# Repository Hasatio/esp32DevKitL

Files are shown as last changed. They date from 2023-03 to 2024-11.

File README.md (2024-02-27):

# ESP32-DEVKIT-L

The circuit taken as an example while designing the board [Olimex ESP32-Gateway](https://www.olimex.com/Products/IoT/ESP32/ESP32-GATEWAY)

## Revision 0

### Added:
- 1x TCA9548 mux IC
- 8x QWIIC connector
- 2x2 Molex connector for for external power supply
- 1x K7805-2000R3L or K7805-2000R3 for 5v convert
- Logo

### Changed:
- Type C
- ESP32-WROOM-32D model
- K7803-2000R3L or K7803-2000R3 for 5V to 3.3V convert
- Texts in pinout

## Revision 1

### Added:
- QWIIC connector pinout

## Revision 2

### Changed:
- Led GPIO33 to GPIO35
- PCA9548's SDA pin GPIO16 to GPIO33

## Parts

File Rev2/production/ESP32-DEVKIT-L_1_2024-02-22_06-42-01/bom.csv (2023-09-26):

Designator | Footprint | Quantity | Value | LCSC Part #
_2, |  | 2
BUT1, RST1 | T1107A(6x3,8x2,5MM) | 2 | T1107A(6x3,8x2,5MM)
C1 | CP_Elec_10x10.5 | 1 | 220uF/50V/10*10mm
C10, C13, C2, C5, C6 | 0603 | 5 | 22uF/6.3V/20%/X5R/C0603
C11, C19, C21 | 1210 | 3 | 330uF/6.3V/20%/X5R/C1210
C12, C14, C15, C16, C18, C23, C7 | 0603 | 7 | 100nF/50V/20%/Y5V/C0603
C17 | 0603 | 1 | 2.2uF/6.3V/10%/X5R/C0603
C20 | 0603 | 1 | NA(10uF/6.3V/20%/X5R/C0603)
C22 | 0603 | 1 | 1uF/C0603
C24 | 0805 | 1 | 47uF/6.3V/20%/X5R/C0805
C25, C26, C27, C28, C29, C30, C31, C32 | 0603 | 8 | 1uF/6.3V/20%/X5R/C0603
C3 | 1206 | 1 | 1nF/2000V/10%/X7R/C1206
C4 | 1206 | 1 | NA(1nF/2000V/10%/X7R/C1206)
C8, C9 | 0603 | 2 | 27pF/50V/5%/C0G/C0603
CON1 | HN1x20 | 1 | NA(NH1x20)
D1 | SMA-KA | 1 | 1N5822/SS34/SMA
D2 | DO214AA_1(K)-2(A) | 1 | SMBJ6.0A(DO-214AA)
D3, D4 | SOD-123_1C-2A_KA | 2 | 1N5819S4/SOD123
D5 | SOT23-3 | 1 | BAT54C(SOT23-3)
FET1, FET2 | SOT23 | 2 | WPM2015-3/TR
GND1 | TESTPAD_40-ROUND | 1 | TESTPAD
I²C0, I²C1, I²C2, I²C3, I²C4, I²C5, I²C6, I²C7 | JST_SH_SM04B-SRSS-TB_1x04-1MP_P1.00mm_Horizontal | 8 | Conn_01x04_P1.00mm_Stemma qt/Qwiic
J1 | Molex_Mini-Fit_Jr_5569-04A1_2x02_P4.20mm_Horizontal | 1 | Conn_02x02_P4.20mm_Molex_Horizontal
L1, L2, L3 | L_0805_5MIL_DWS | 3 | FB0805/600R/2A
LAN1 | RJLBC-060TC1 | 1 | RJLD-060TC1(LPJ4013EDNL)
LED | SJ | 1 | Closed
LED1 | LED_0603_KA | 1 | LED/GREEN/0603
MH1, MH2 | Mounting_hole_Shield_3.3mm | 2 | Mounting_hole_Shield_3.3mm
MICRO_SD1 | TFC-WXCP11-08-LF | 1 | TFC-WXCP11-08-LF
PWRLED1 | LED_0603_KA | 1 | LED/RED/0603
Q1 | Q_49U3HMS | 1 | Q12MHz/20pF/30ppm/2P/HC-49SM(SMD)
Q2, Q3 | SOT23 | 2 | BC817-40(SOT23)
R1, R15, R16 | 0603 | 3 | 1k/R0603
R10, R7, R8, R9 | 0603 | 4 | 49.9R/1%/R0603
R11, R12, R18, R2, R20, R22, R27, R52 | 0603 | 8 | 10k/R0603
R13 | 0603 | 1 | 1M/R0603
R14, R21, R23, R24, R25, R37 | 0603 | 6 | 2.2k/R0603
R17, R40, R51 | 0603 | 3 | 220R/R0603
R19 | 0603 | 1 | 12.1k/1%/R0603
R26, R28, R29, R30, R31, R32, R33, R34, R35, R36, R43, R44, R45, R46, R47, R48, R49, R50 | 0603 | 18 | 4.7k/R0603
R3, R4 | 0603 | 2 | 5.1k/R0603
R38, R41, R42, R53 | 0603 | 4 | NA/R0603
R39 | 0603 | 1 | 10R/R0603
R5, R6 | 0603 | 2 | 330R/R0603
RESET | SJ | 1 | Opened
RM1, RM2 | R_MATRIX_4 | 2 | RA1206_(4X0603)_4B8_2.2k
Sign-Antistatic | LOGO_ANTISTATIC_1 | 1 | Val**
Sign-RecyclBin | LOGO_RECYCLEBIN_1 | 1
Sign_Pb-Free | LOGO_PBFREE | 1
Sign_RoHS | LOGO_ROHS_1 | 1 | Val**
T1 | SOT23 | 1 | DTC114YKA
U1 | USB2.0_TYPE-C(A40-00119-A52-12) | 1 | USB-C-16P-F(A40-00119-A52-12)
U2 | Converter_DCDC_RECOM_R-78HB-0.5L_THT | 1 | K7805-2000R3L
U3 | SSOP-20W | 1 | CH340T(SSOP20W)
U4 | QFN32_EP(33)_5.00x5.00x0.90mm_Pitch_0.50mm | 1 | LAN8710A-EZC(QFN32)
U5 | Converter_DCDC_RECOM_R-78HB-0.5L_THT | 1 | K7803-2000R3L
U6 | TSSOP-24_4.4x7.8mm_P0.65mm | 1 | TCA9548APWR
U7 | ESP-WROOM-32_MODULE | 1 | ESP32-WROOM-32D-4MB

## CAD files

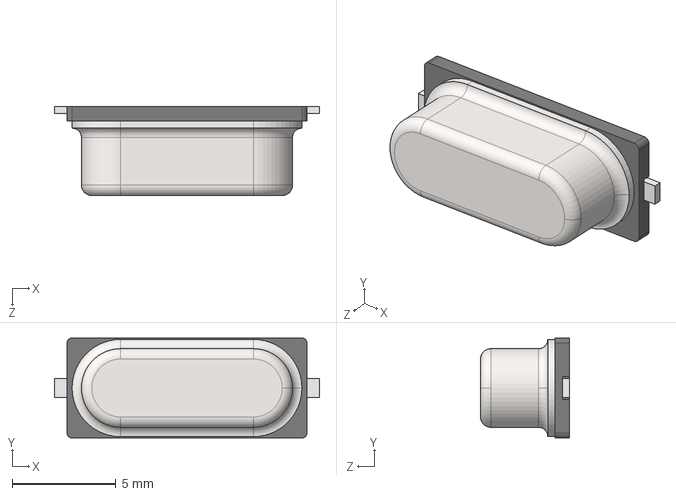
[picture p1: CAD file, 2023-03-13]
Rev2/3d/User_Library-Crystal_HC49_US-SM.step
12.8 x 4.83 x 4.30 mm

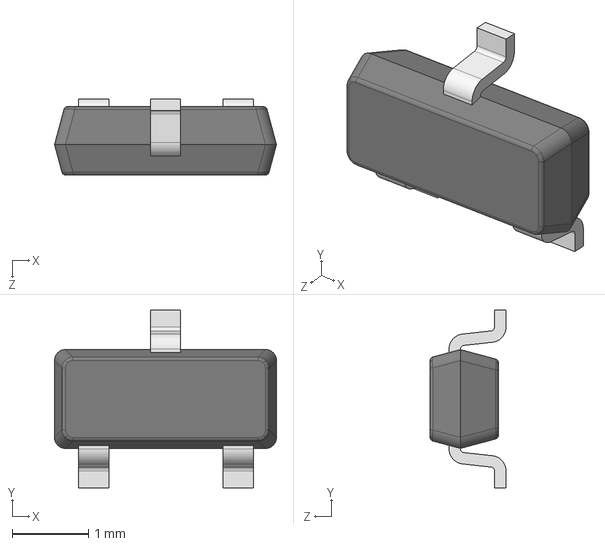
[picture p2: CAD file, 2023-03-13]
Rev2/3d/BAT54.step
2.92 x 2.34 x 1.00 mm

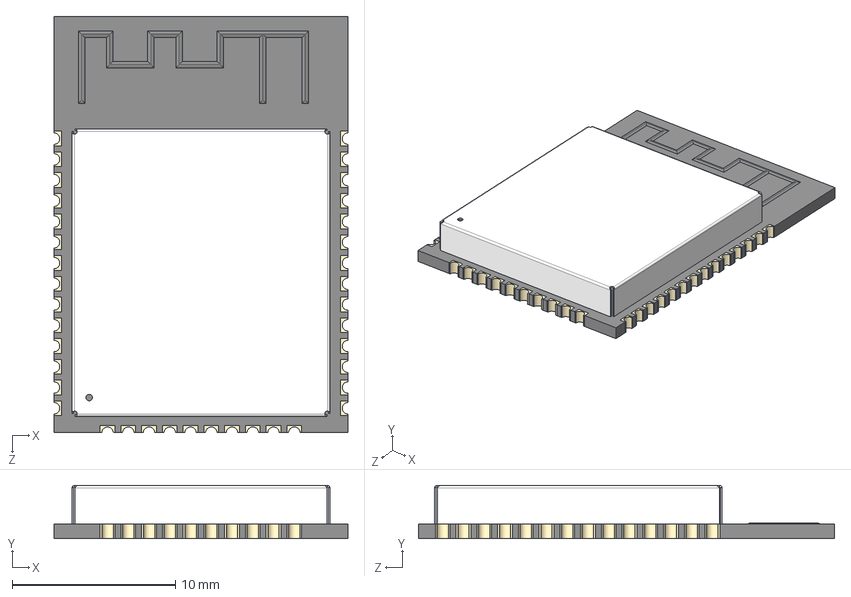
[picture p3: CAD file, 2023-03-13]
Rev2/3d/ESP32-WROOM-32D-56544.STEP
18.0 x 3.25 x 25.5 mm

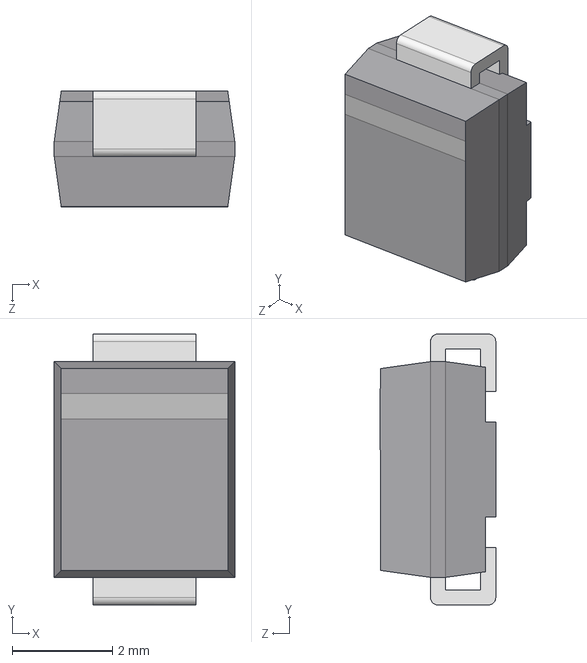
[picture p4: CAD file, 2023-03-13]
Rev2/3d/DO-214AA_SMB.step
3.60 x 5.40 x 2.30 mm

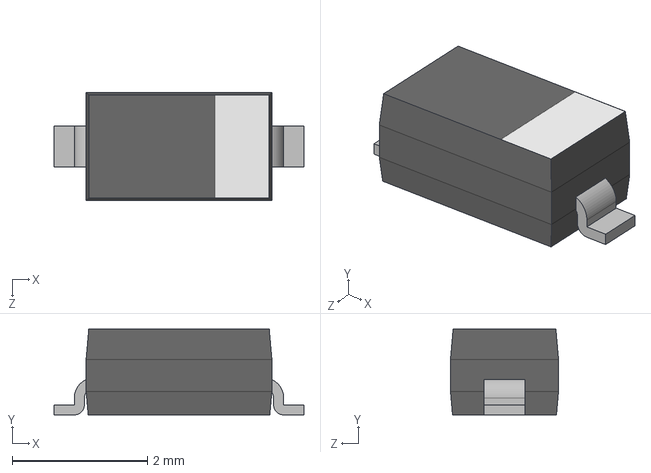
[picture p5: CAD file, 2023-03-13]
Rev2/3d/SOD123.step
3.70 x 1.27 x 1.60 mm

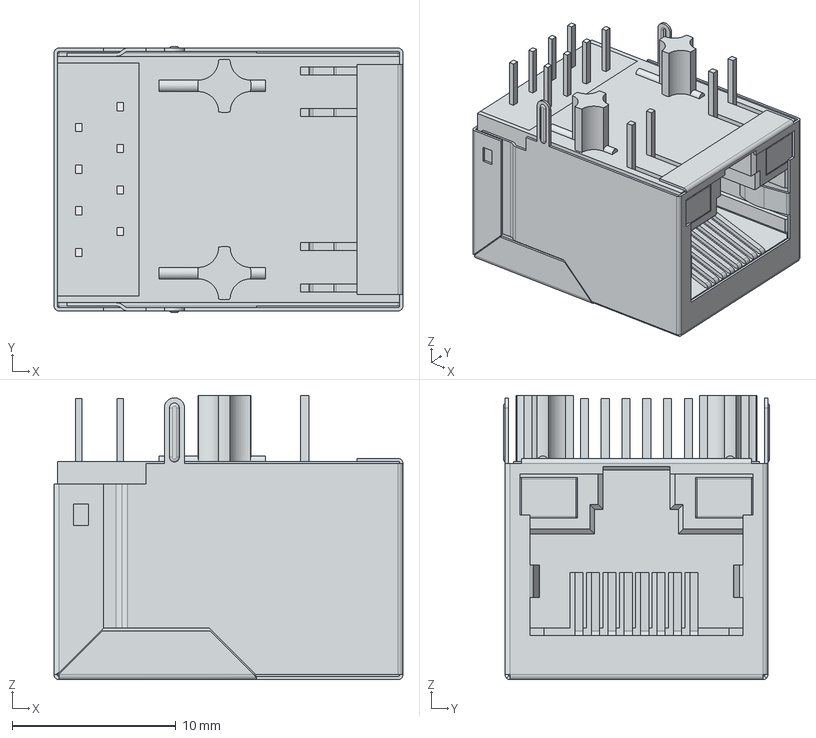
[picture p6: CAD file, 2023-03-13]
Rev2/3d/Connector_1Port_RJ45_Magjack_10-100Base-T_AutoMDIX_Wurth_Electronics-7499010441.stp
21.3 x 16.2 x 17.4 mm
Shielding
Insulator 3
Insulator 1
Insulator 2
Green_Yellow_LED x 2

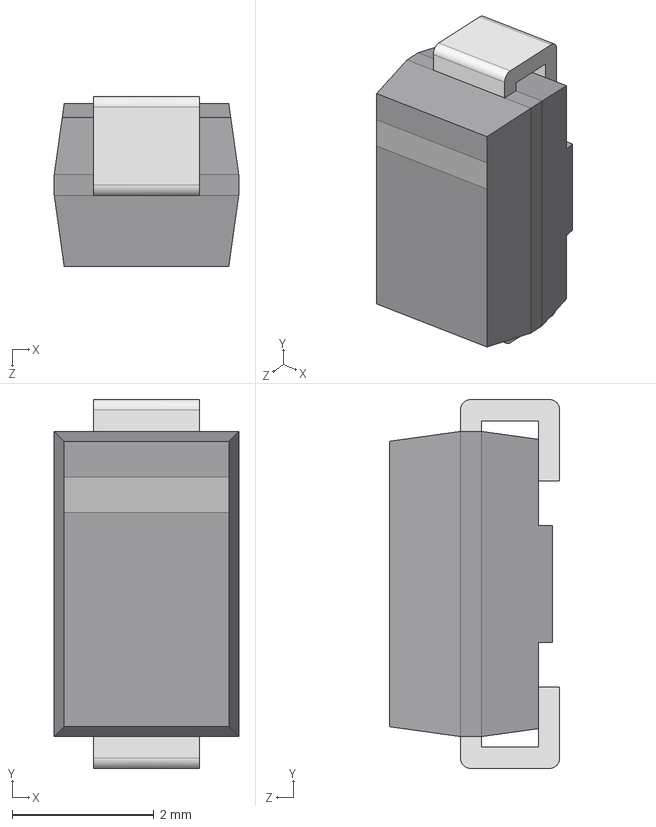
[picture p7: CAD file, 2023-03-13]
Rev2/3d/DO-214AC_SMA.step
2.60 x 5.20 x 2.40 mm

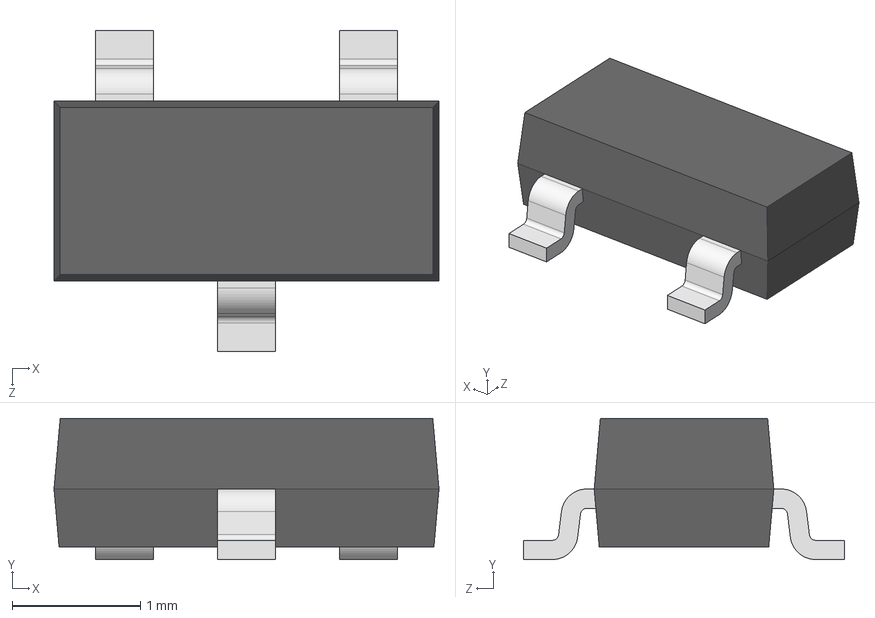
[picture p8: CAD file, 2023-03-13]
Rev2/3d/SOT-23.step
3.00 x 1.10 x 2.50 mm

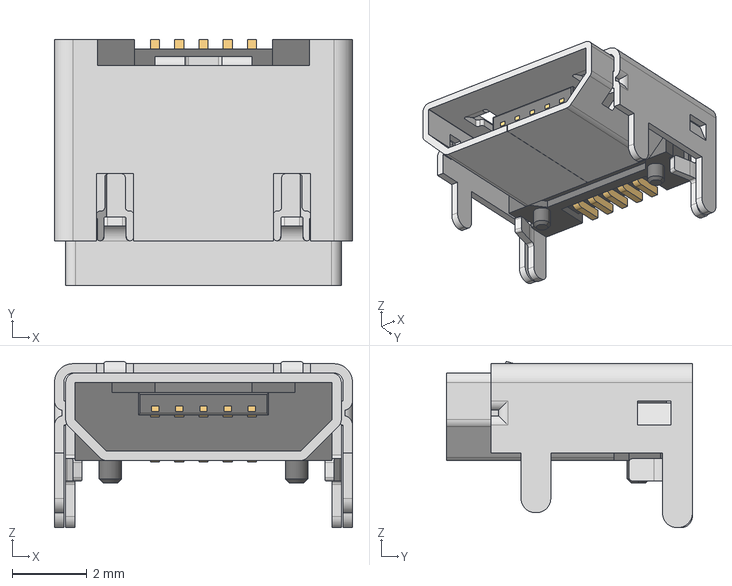
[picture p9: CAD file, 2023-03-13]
Rev2/3d/usb_micro_4p.stp
8.00 x 6.60 x 4.46 mm

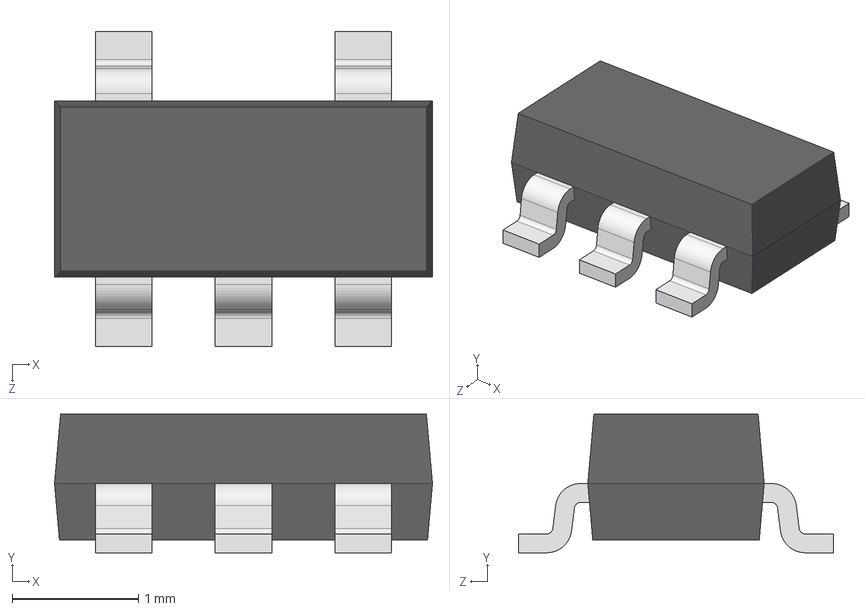
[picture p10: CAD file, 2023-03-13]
Rev2/3d/SOT-23-5.step
3.00 x 1.10 x 2.50 mm

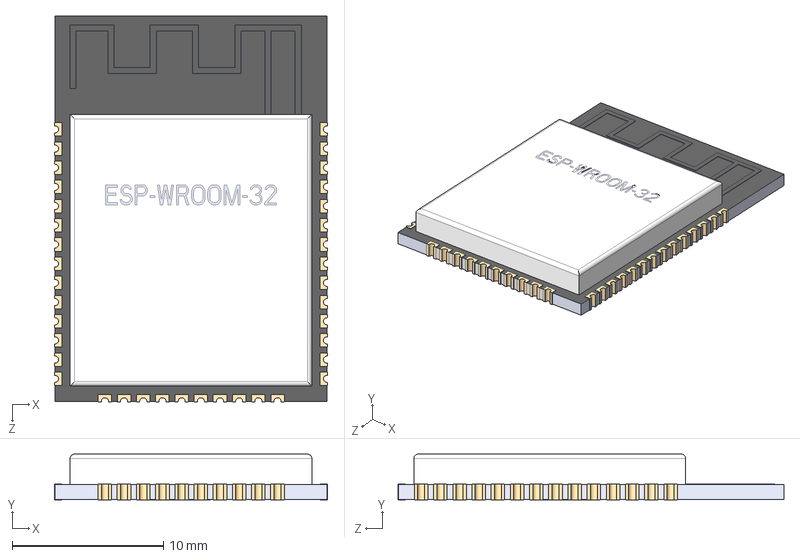
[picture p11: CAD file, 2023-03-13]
Rev2/3d/esp-wroom-32.step
18.1 x 3.04 x 25.5 mm

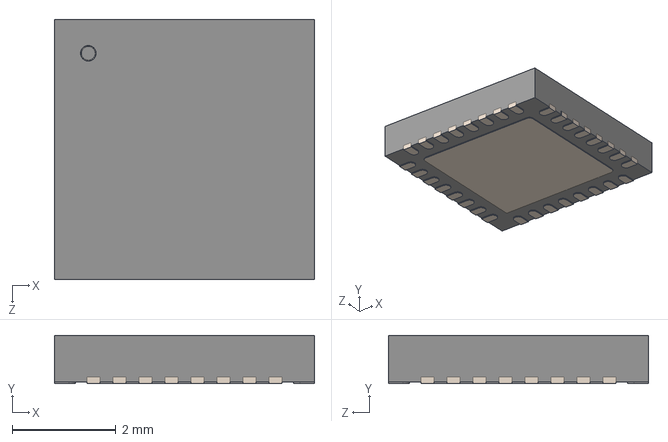
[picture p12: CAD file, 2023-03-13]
Rev2/3d/QFN32_5x5.step
5.00 x 0.93 x 5.00 mm

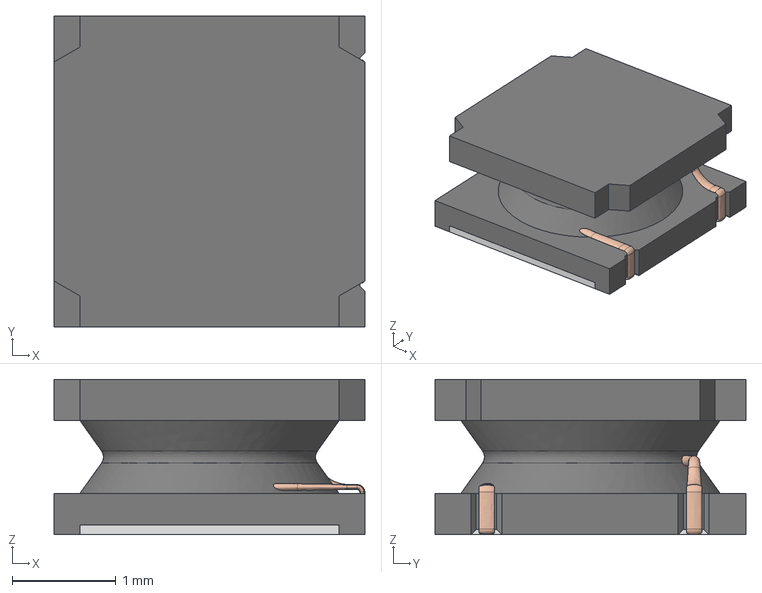
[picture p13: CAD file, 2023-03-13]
Rev2/3d/L-CD32_shielded.step
3.00 x 3.00 x 1.50 mm

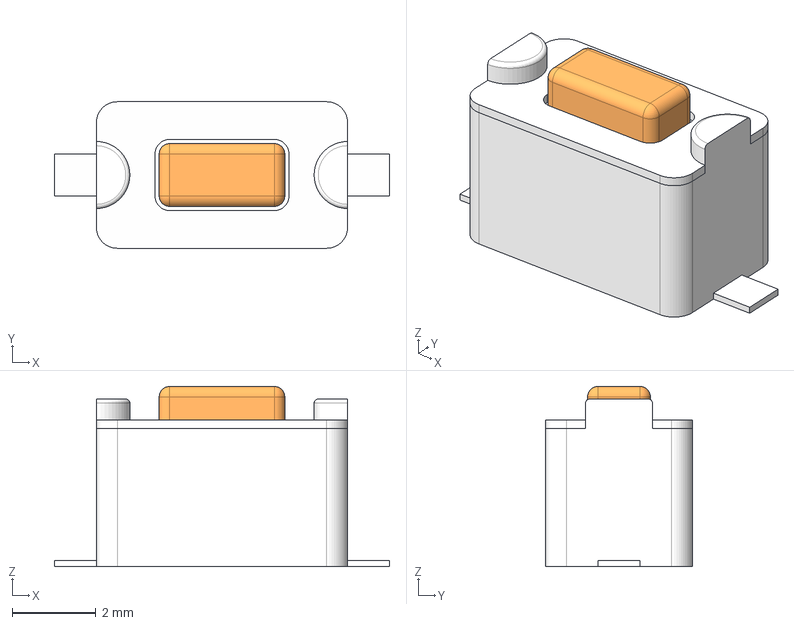
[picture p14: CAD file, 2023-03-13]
Rev2/3d/434121043836 (rev1).stp
8.00 x 3.50 x 4.30 mm
Frame
Cover
pins x 2

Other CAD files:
Rev2/3d/5040771891.stp

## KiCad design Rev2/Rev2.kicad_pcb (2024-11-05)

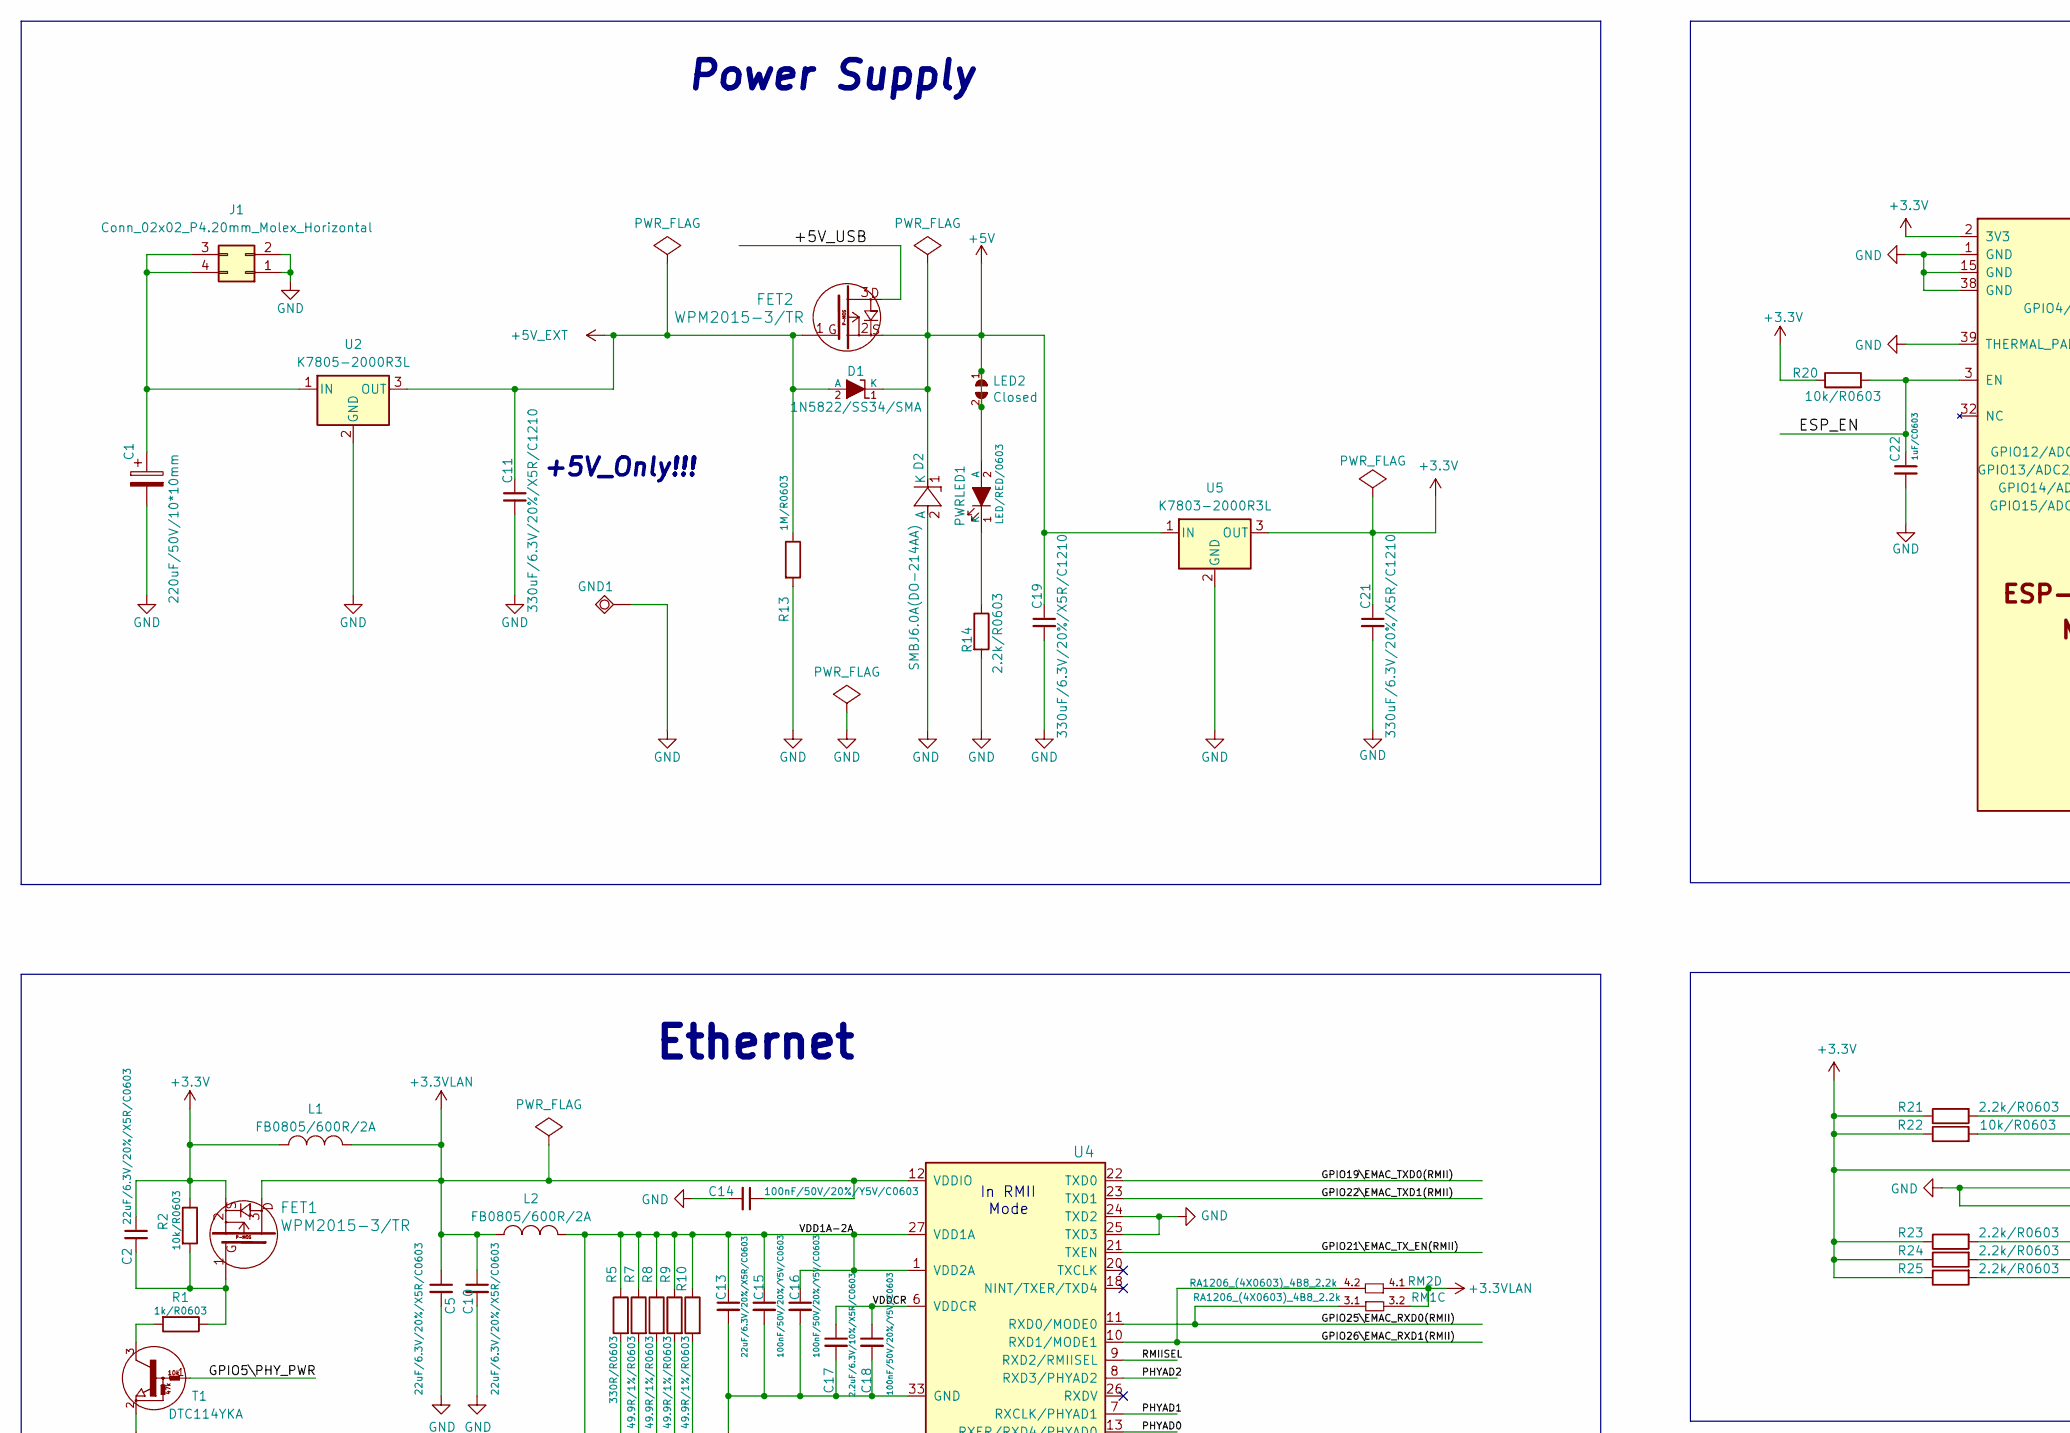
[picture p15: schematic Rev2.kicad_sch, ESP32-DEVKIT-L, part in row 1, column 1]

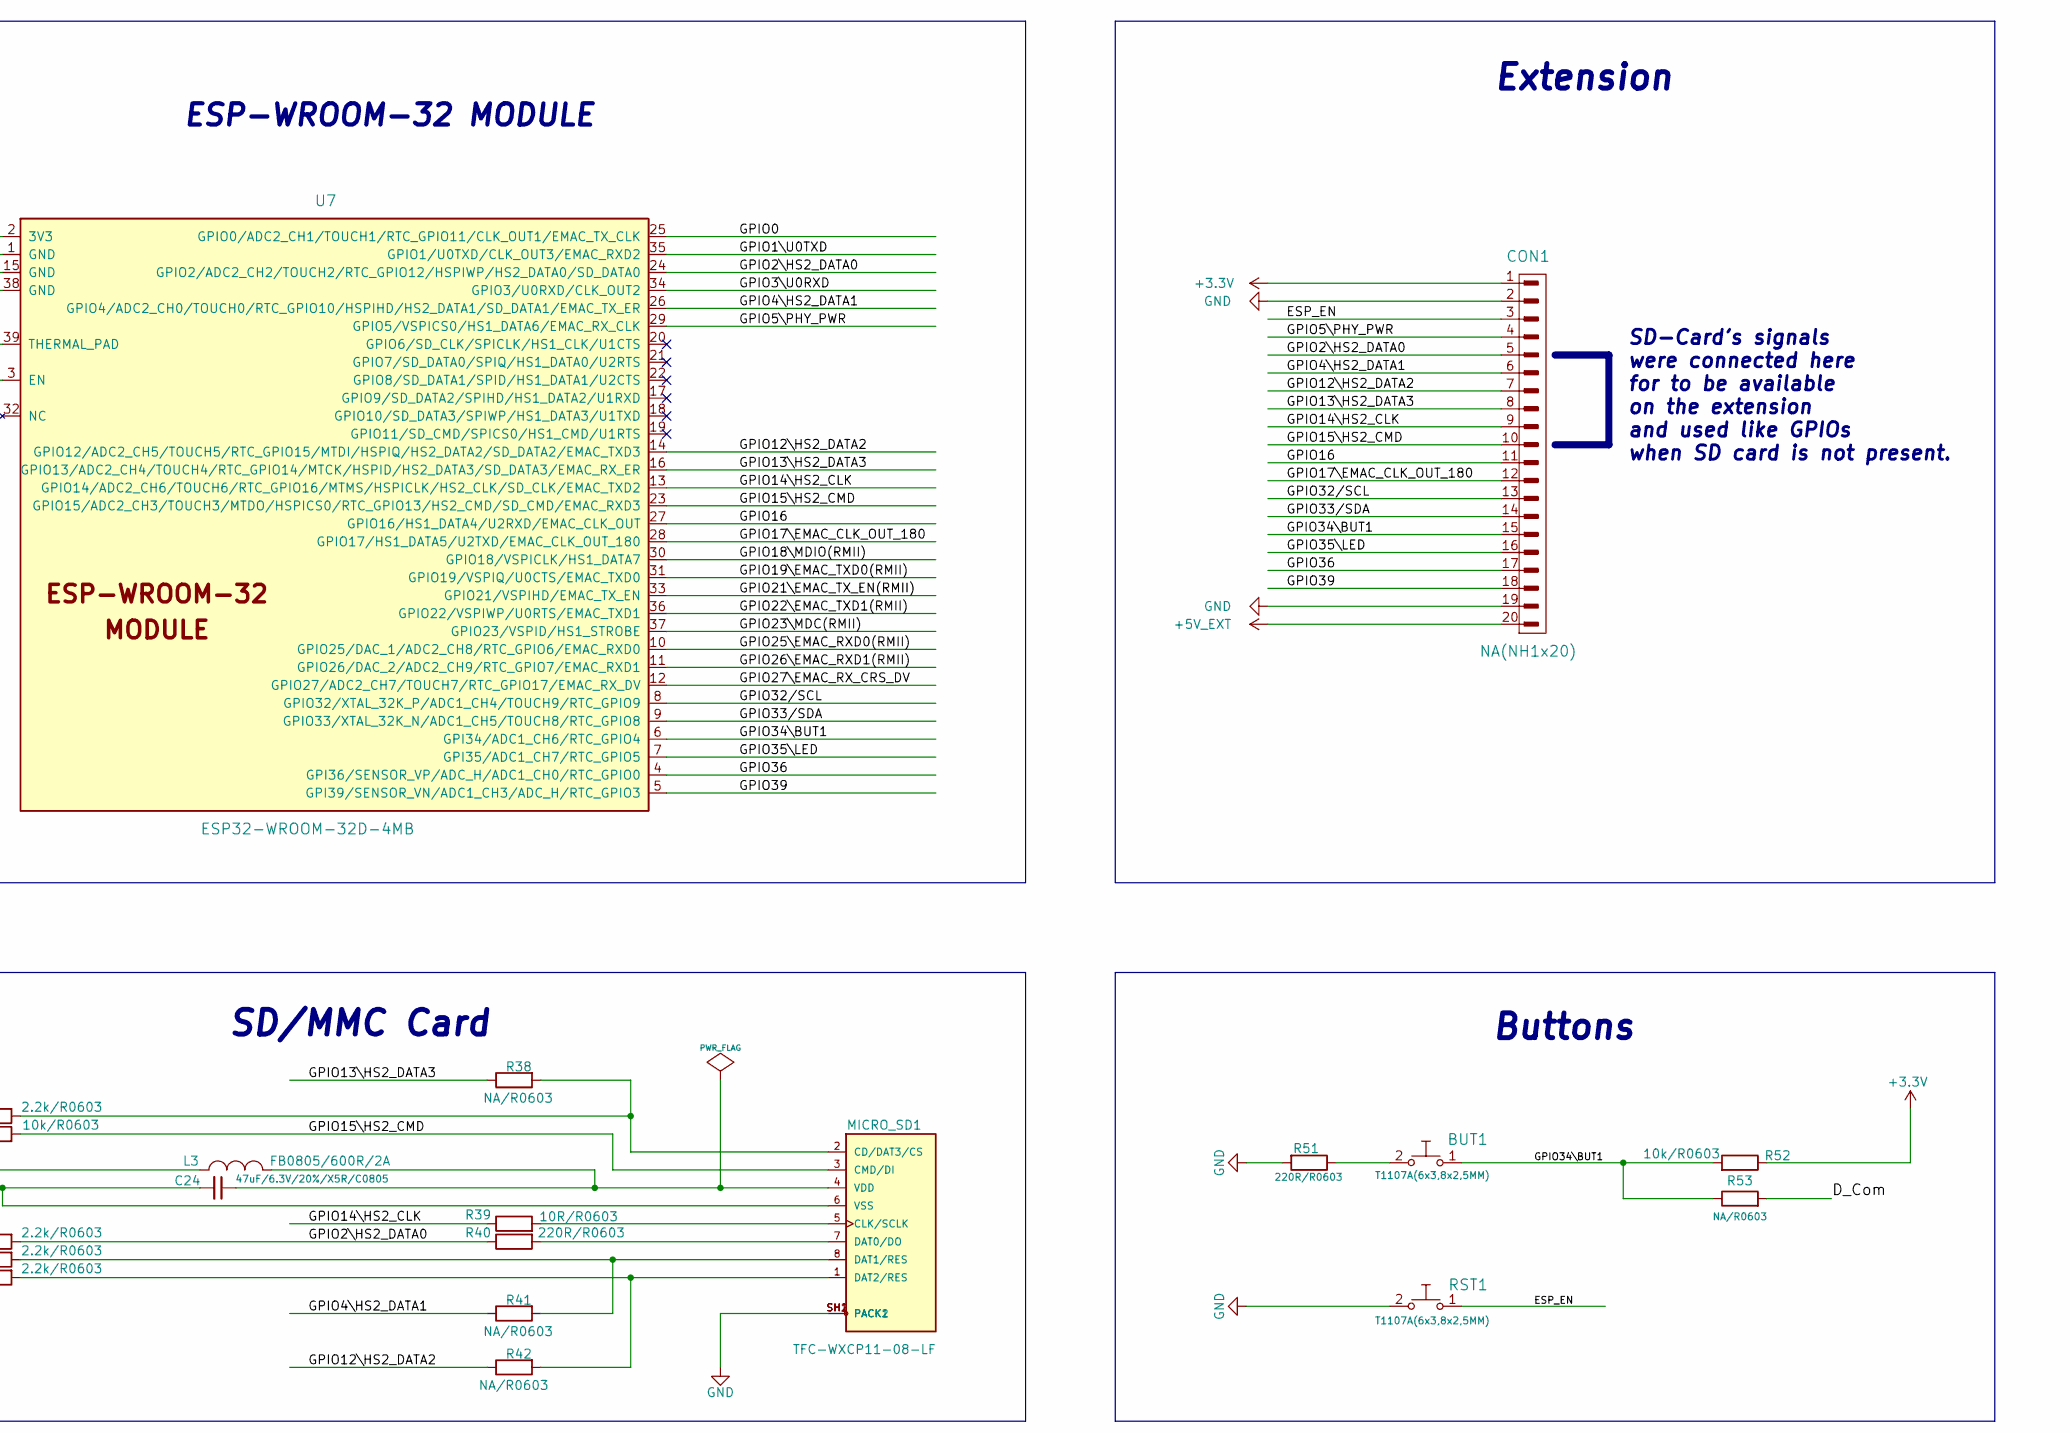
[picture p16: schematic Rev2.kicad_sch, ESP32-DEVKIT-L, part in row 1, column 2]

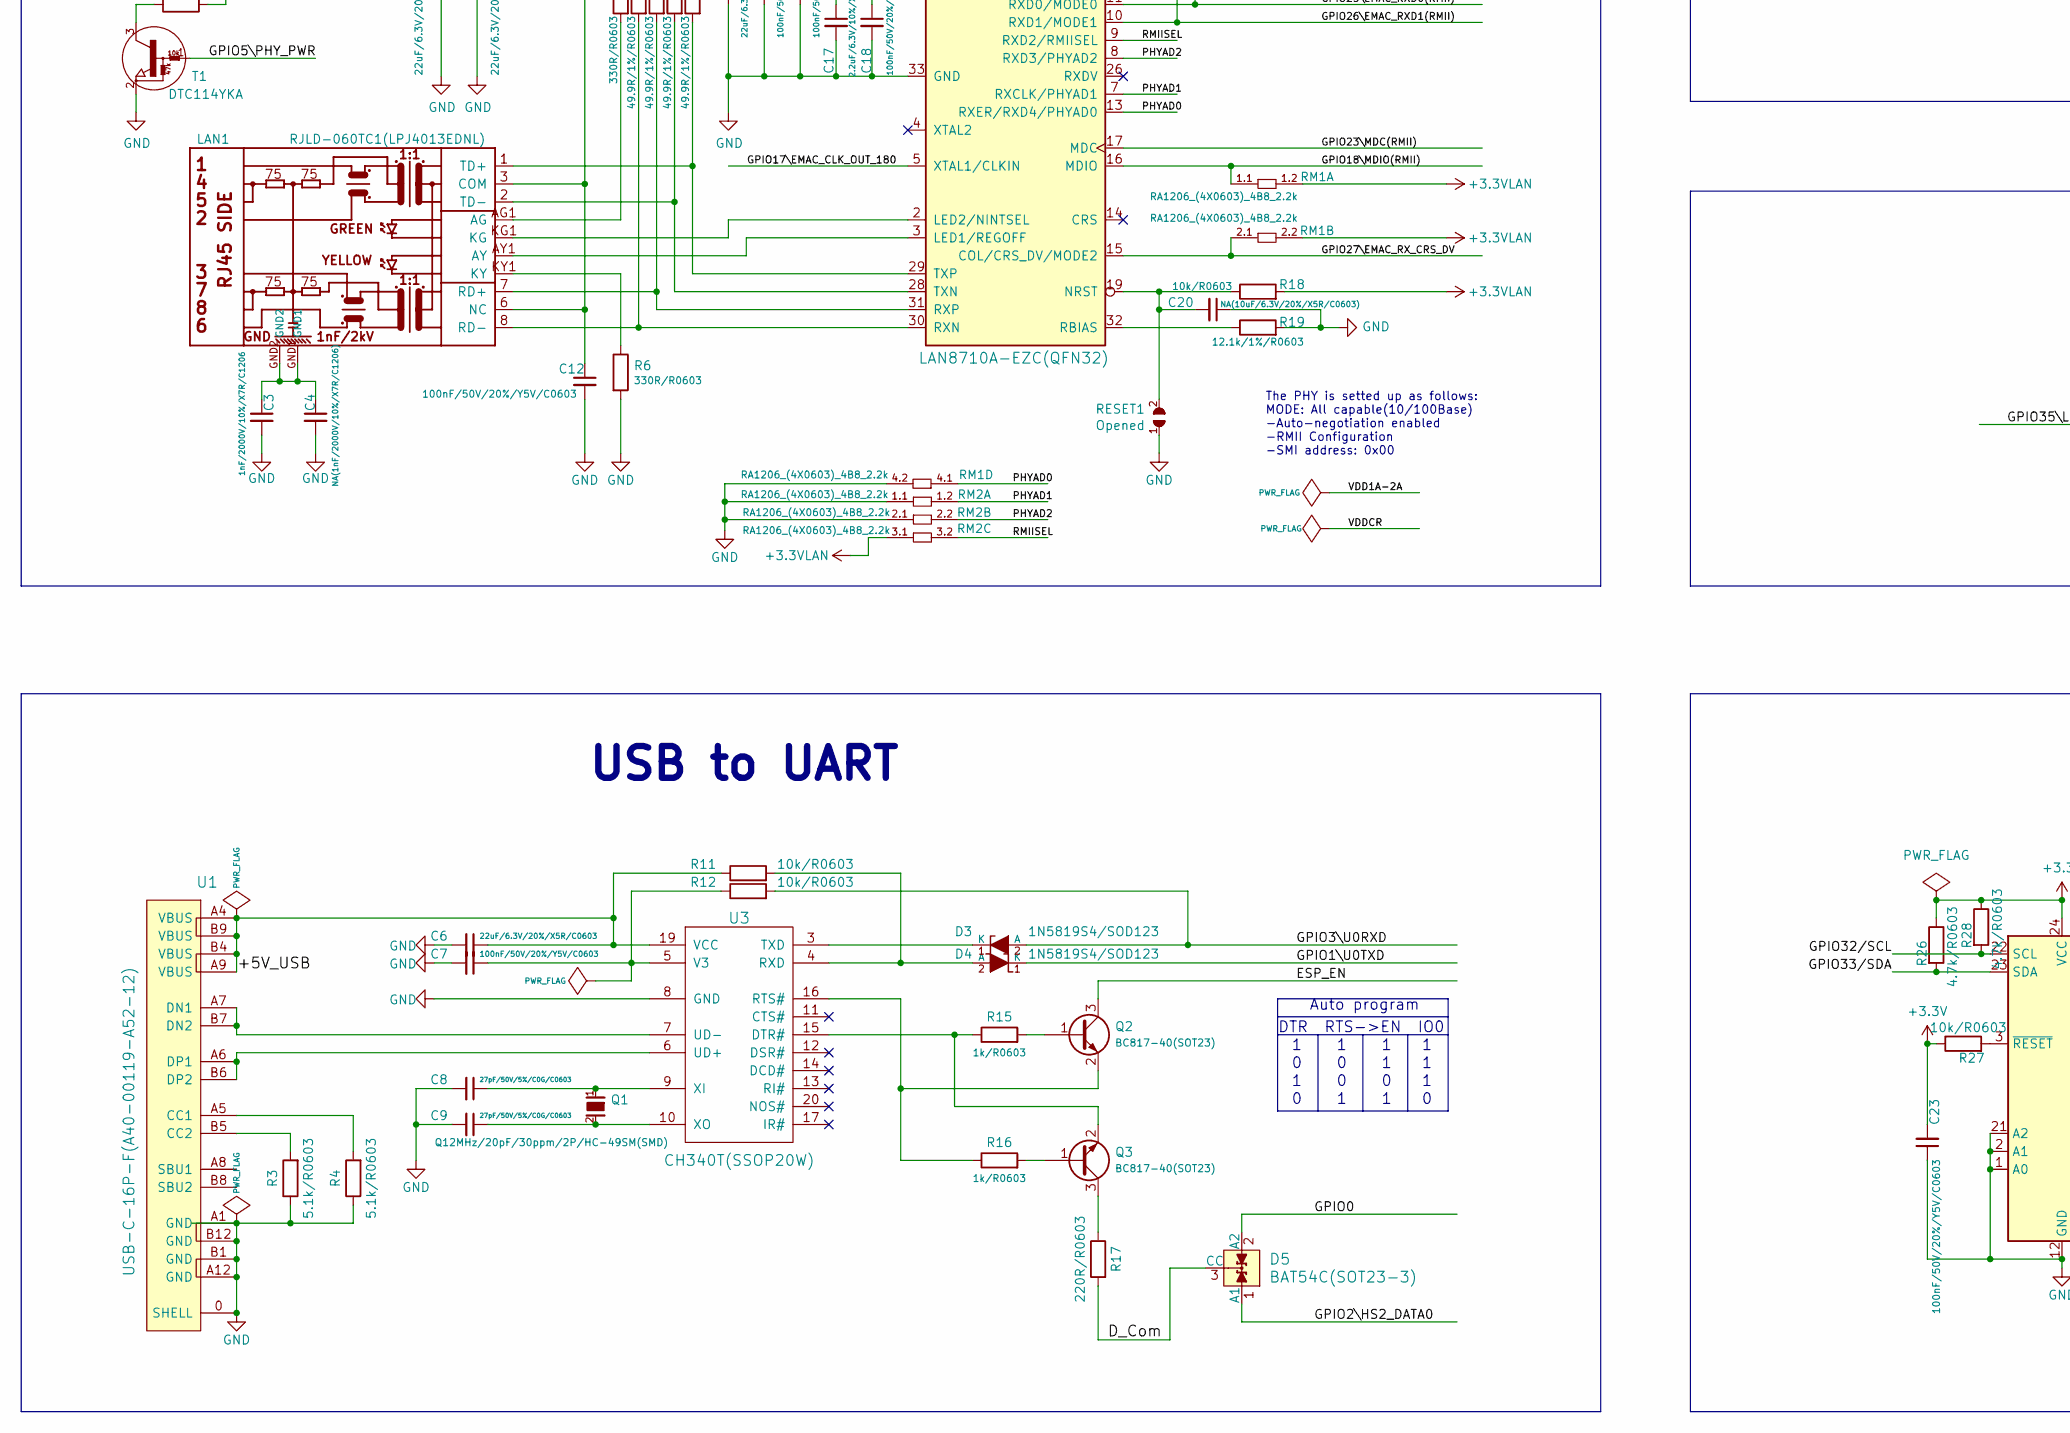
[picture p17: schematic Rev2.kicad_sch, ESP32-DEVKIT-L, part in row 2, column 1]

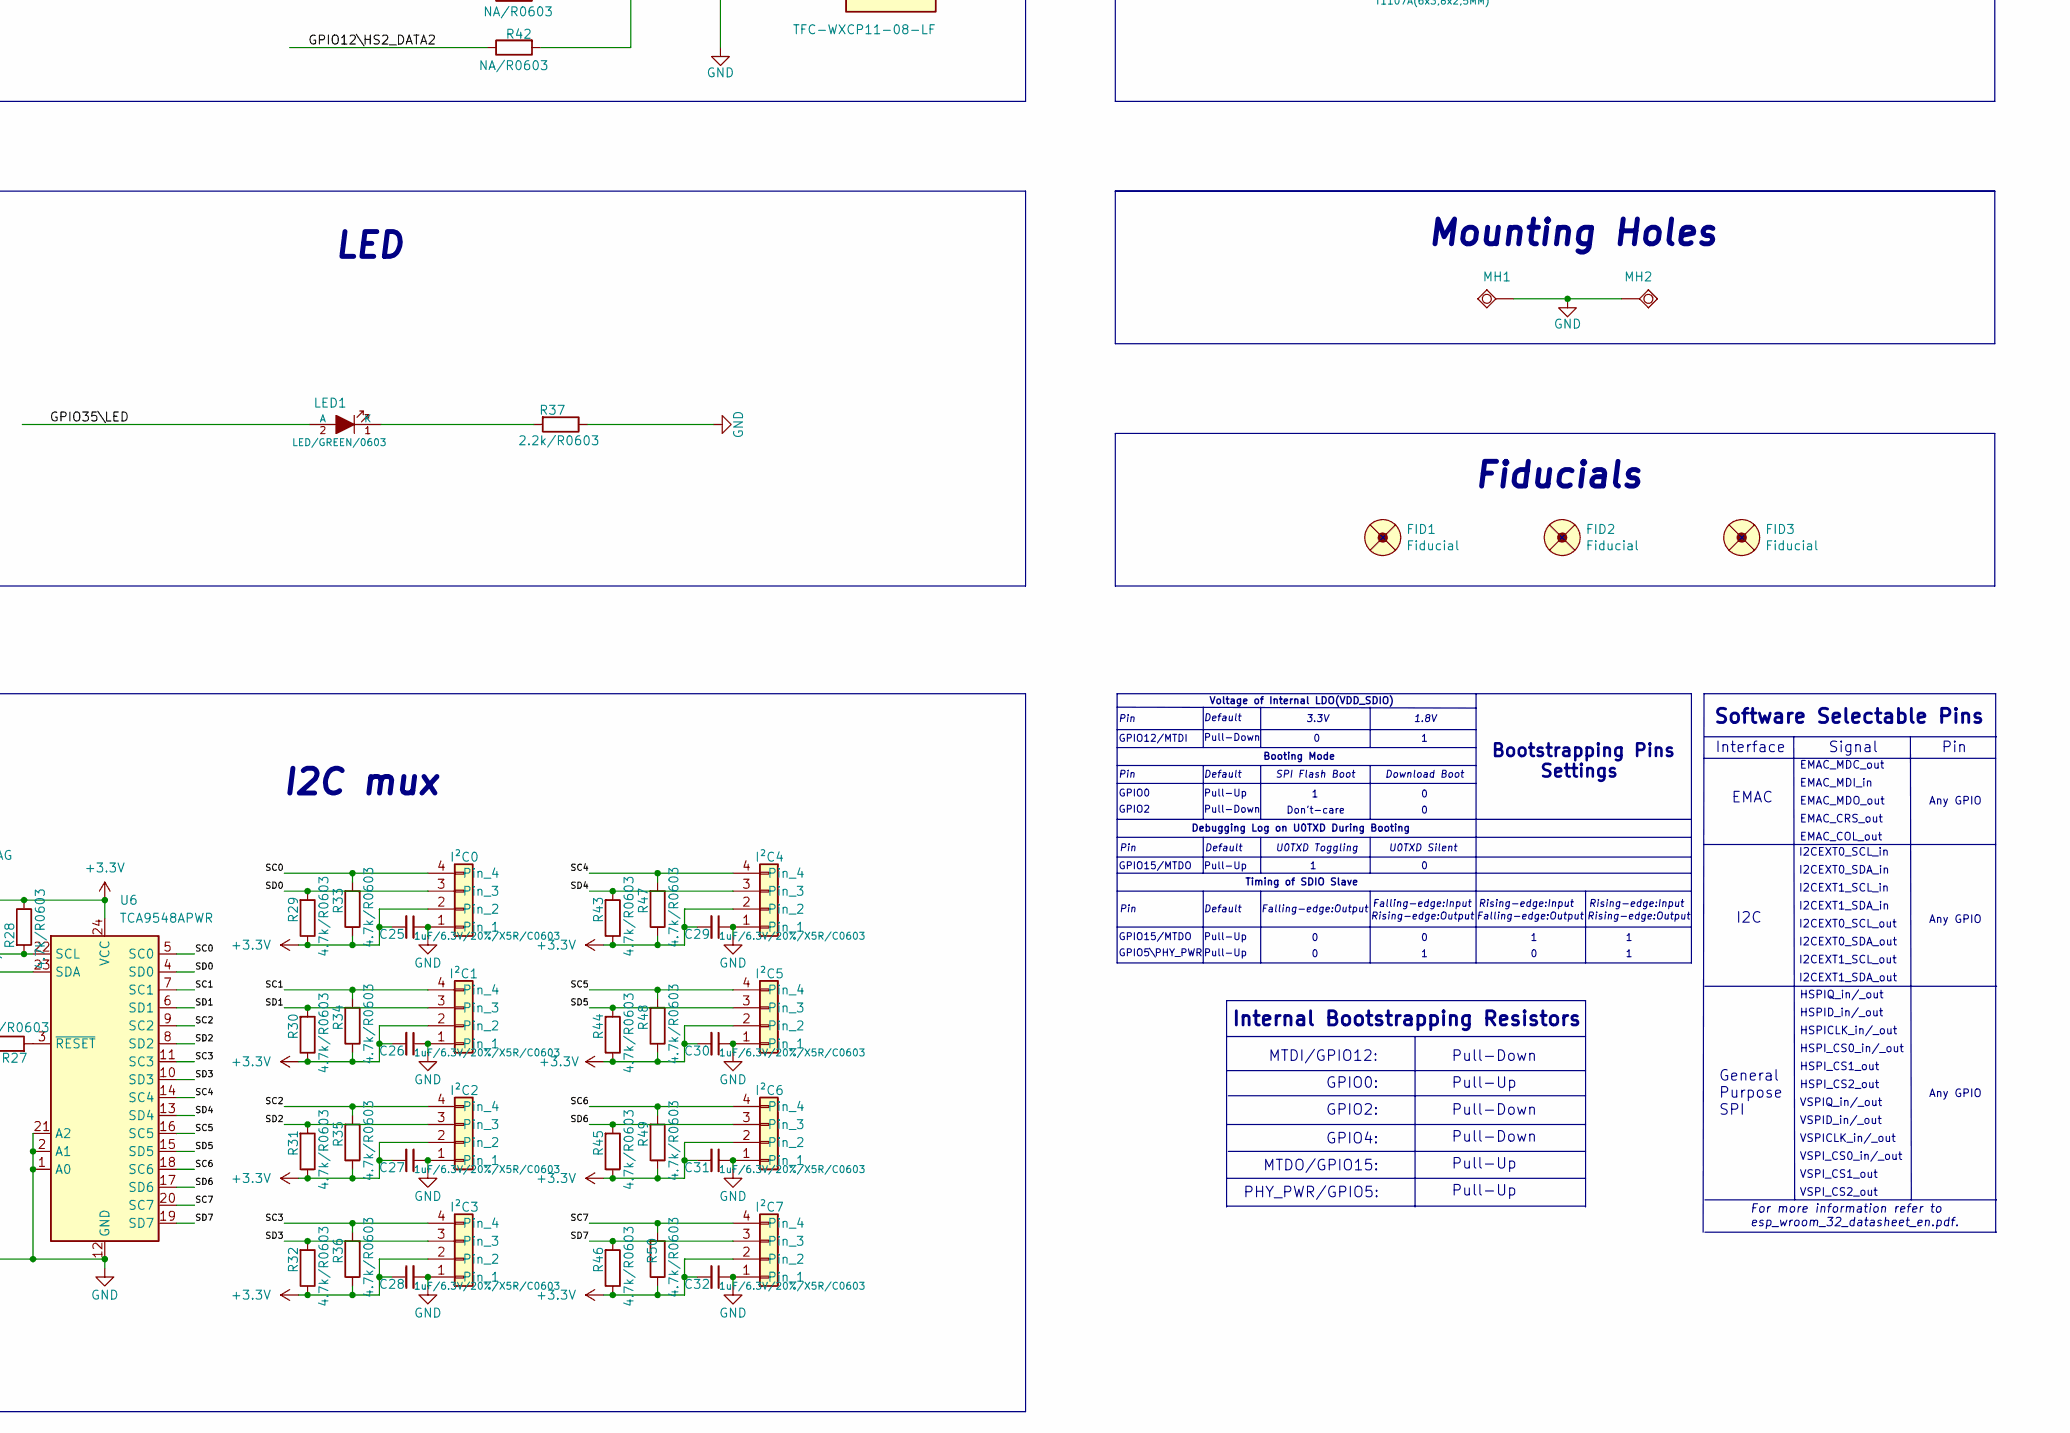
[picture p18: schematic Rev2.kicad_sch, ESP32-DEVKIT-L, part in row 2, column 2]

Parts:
BUT1: T1107A(6x3,8x2,5MM)
C1: 220uF/50V/10*10mm; CP_Elec_10x10.5
C2, C5, C6, C10, C13: 22uF/6.3V/20%/X5R/C0603; 0603
C3: 1nF/2000V/10%/X7R/C1206; 1206
C4: NA(1nF/2000V/10%/X7R/C1206); 1206
C7, C12, C14, C15, C16, C18, C23: 100nF/50V/20%/Y5V/C0603; 0603
C8, C9: 27pF/50V/5%/C0G/C0603; 0603
C11, C19, C21: 330uF/6.3V/20%/X5R/C1210; 1210
C17: 2.2uF/6.3V/10%/X5R/C0603; 0603
C20: NA(10uF/6.3V/20%/X5R/C0603); 0603
C22: 1uF/C0603; 0603
C24: 47uF/6.3V/20%/X5R/C0805; 0805
C25, C26, C27, C28, C29, C30, C31, C32: 1uF/6.3V/20%/X5R/C0603; 0603
CON1: NA(NH1x20); HN1x20
D1: 1N5822/SS34/SMA; SMA-KA
D2: SMBJ6.0A(DO-214AA); DO214AA_1(K)-2(A)
D3, D4: 1N5819S4/SOD123; SOD-123_1C-2A_KA
D5: BAT54C(SOT23-3); SOT23-3
FET1, FET2: WPM2015-3/TR; SOT23
FID1, FID2, FID3: Fiducial; Fiducial1x3
GND1: TESTPAD; TESTPAD_40-ROUND
I²C0, I²C1, I²C2, I²C3, I²C4, I²C5, I²C6, I²C7: Conn_01x04_P1.00mm_Stemma qt/Qwiic; JST_SH_SM04B-SRSS-TB_1x04-1MP_P1.00mm_Horizontal
J1: Conn_02x02_P4.20mm_Molex_Horizontal; Molex_Mini-Fit_Jr_5569-04A1_2x02_P4.20mm_Horizontal
L1, L2, L3: FB0805/600R/2A; L_0805_5MIL_DWS
LAN1: RJLD-060TC1(LPJ4013EDNL); RJLBC-060TC1
LED1: LED/GREEN/0603; LED_0603_KA
LED2: Closed; SJ
MH1, MH2: Mounting_hole_Shield_3.3mm
MICRO_SD1: TFC-WXCP11-08-LF
PWRLED1: LED/RED/0603; LED_0603_KA
Q1: Q12MHz/20pF/30ppm/2P/HC-49SM(SMD); Q_49U3HMS
Q2, Q3: BC817-40(SOT23); SOT23
R1, R15, R16: 1k/R0603; 0603
R2, R11, R12, R18, R20, R22, R27, R52: 10k/R0603; 0603
R3, R4: 5.1k/R0603; 0603
R5, R6: 330R/R0603; 0603
R7, R8, R9, R10: 49.9R/1%/R0603; 0603
R13: 1M/R0603; 0603
R14, R21, R23, R24, R25, R37: 2.2k/R0603; 0603
R17, R40, R51: 220R/R0603; 0603
R19: 12.1k/1%/R0603; 0603
R26, R28, R29, R30, R31, R32, R33, R34, R35, R36, R43, R44, R45, R46, R47, R48, R49, R50: 4.7k/R0603; 0603
R38, R41, R42, R53: NA/R0603; 0603
R39: 10R/R0603; 0603
RESET1: Opened; SJ
RM1, RM2: RA1206_(4X0603)_4B8_2.2k; R_MATRIX_4
RST1: T1107A(6x3,8x2,5MM)
T1: DTC114YKA; SOT23
U1: USB-C-16P-F(A40-00119-A52-12); USB2.0_TYPE-C(A40-00119-A52-12)
U2: K7805-2000R3L; Converter_DCDC_RECOM_R-78HB-0.5L_THT
U3: CH340T(SSOP20W); SSOP-20W
U4: LAN8710A-EZC(QFN32); QFN32_EP(33)_5.00x5.00x0.90mm_Pitch_0.50mm
U5: K7803-2000R3L; Converter_DCDC_RECOM_R-78HB-0.5L_THT
U6: TCA9548APWR; TSSOP-24_4.4x7.8mm_P0.65mm
U7: ESP32-WROOM-32D-4MB; ESP-WROOM-32_MODULE

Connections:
+3.3VLAN: C5.1, C10.1, C14.1, FET1.3, L1.2, L2.1, R18.2, RM1.1.2, RM1.2.2, RM1.3.2, RM2.3.1, RM2.4.1, U4.12 (VDDIO)
+3V3: C2.1, C21.1, C23.2, C25.2, C26.2, C27.2, C28.1, C29.2, C30.2, C31.2, C32.2, CON1.1, FET1.2, I²C0.2, I²C1.2, I²C2.2, I²C3.2, I²C4.2, I²C5.2, I²C6.2, I²C7.2, L1.1, L3.1, R2.1, R20.1, R21.1, R22.1, R23.1, R24.1, R25.1, R26.1, R27.1, R28.1, R29.1, R30.1, R31.1, R32.1, R33.1, R34.1, R35.1, R36.1, R43.1, R44.1, R45.1, R46.1, R47.1, R48.1, R49.1, R50.1, R52.1, U5.3 (OUT), U6.24 (VCC), U7.2 (3V3)
+5V: C19.1, D1.1 (K), D2.1 (K), FET2.2, LED2.1, LED2.2, PWRLED1.2 (A), U5.1 (IN); also elsewhere on the board
+5V_EXT: C11.1, CON1.20, D1.2 (A), FET2.1, R13.1, U2.3 (OUT)
/+5V_USB: C6.1, FET2.3, R11.1, U1.A4 (VBUS), U1.A9 (VBUS), U1.B4 (VBUS), U1.B9 (VBUS), U3.19 (VCC)
/D_Com: D5.3 (CC), R17.2, R53.2
/ESP_EN: C22.1, CON1.3, Q2.3 (C), R20.2, RST1.1, U7.3 (EN)
/GPIO0: D5.2 (A2), U7.25 (GPIO0/ADC2_CH1/TOUCH1/RTC_GPIO11/CLK_OU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)
/GPIO1\U0TXD: D4.1 (K), U7.35 (GPIO1/U0TXD/CLK_OUT3/EMAC_RXD2)
/GPIO2\HS2_DATA0: CON1.5, D5.1 (A1), R23.2, R40.1, U7.24 (GPIO2/ADC2_CH2/TOUCH2/RTC_GPIO12/HSPIWP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)
/GPIO3\U0RXD: D3.2 (A), R12.2, U7.34 (GPIO3/U0RXD/CLK_OUT2)
/GPIO4\HS2_DATA1: CON1.6, R41.1, U7.26 (GPIO4/ADC2_CH0/TOUCH0/RTC_GPIO10/HSPIHD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)
/GPIO5\PHY_PWR: CON1.4, T1.1 (B), U7.29 (GPIO5/VSPICS0/HS1_DATA6/EMAC_RX_CLK)
/GPIO12\HS2_DATA2: CON1.7, R42.1, U7.14 (GPIO12/ADC2_CH5/TOUCH5/RTC_GPIO15/MTDI/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)
/GPIO13\HS2_DATA3: CON1.8, R38.1, U7.16 (GPIO13/ADC2_CH4/TOUCH4/RTC_GPIO14/MTCK/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)
/GPIO14\HS2_CLK: CON1.9, R39.1, U7.13 (GPIO14/ADC2_CH6/TOUCH6/RTC_GPIO16/MTMS/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)
/GPIO15\HS2_CMD: CON1.10, MICRO_SD1.3 (CMD/DI), R22.2, U7.23 (GPIO15/ADC2_CH3/TOUCH3/MTDO/HSPICS0/RTC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)
/GPIO16: CON1.11, U7.27 (GPIO16/HS1_DATA4/U2RXD/EMAC_CLK_OUT)
/GPIO17\EMAC_CLK_OUT_180: CON1.12, U4.5 (XTAL1/CLKIN), U7.28 (GPIO17/HS1_DATA5/U2TXD/EMAC_CLK_OUT_180)
/GPIO18\MDIO(RMII): RM1.1.1, U4.16 (MDIO), U7.30 (GPIO18/VSPICLK/HS1_DATA7)
/GPIO19\EMAC_TXD0(RMII): U4.22 (TXD0), U7.31 (GPIO19/VSPIQ/U0CTS/EMAC_TXD0)
/GPIO21\EMAC_TX_EN(RMII): U4.21 (TXEN), U7.33 (GPIO21/VSPIHD/EMAC_TX_EN)
/GPIO22\EMAC_TXD1(RMII): U4.23 (TXD1), U7.36 (GPIO22/VSPIWP/U0RTS/EMAC_TXD1)
/GPIO23\MDC(RMII): U4.17 (MDC), U7.37 (GPIO23/VSPID/HS1_STROBE)
/GPIO25\EMAC_RXD0(RMII): RM1.3.1, U4.11 (RXD0/MODE0), U7.10 (GPIO25/DAC_1/ADC2_CH8/RTC_GPIO6/EMAC_RX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)
/GPIO26\EMAC_RXD1(RMII): RM2.4.2, U4.10 (RXD1/MODE1), U7.11 (GPIO26/DAC_2/ADC2_CH9/RTC_GPIO7/EMAC_RX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)
/GPIO27\EMAC_RX_CRS_DV: RM1.2.1, U4.15 (COL/CRS_DV/MODE2), U7.12 (GPIO27/ADC2_CH7/TOUCH7/RTC_GPIO17/EMAC_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)
/GPIO32/SCL: CON1.13, R28.2, U6.22 (SCL), U7.8 (GPIO32/XTAL_32K_P/ADC1_CH4/TOUCH9/RTC_G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)
/GPIO33/SDA: CON1.14, R26.2, U6.23 (SDA), U7.9 (GPIO33/XTAL_32K_N/ADC1_CH5/TOUCH8/RTC_G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)
/GPIO34\BUT1: BUT1.1, CON1.15, R52.2, R53.1, U7.6 (GPI34/ADC1_CH6/RTC_GPIO4)
/GPIO35\LED: CON1.16, LED1.2 (A), U7.7 (GPI35/ADC1_CH7/RTC_GPIO5)
/GPIO36: CON1.17, U7.4 (GPI36/SENSOR_VP/ADC_H/ADC1_CH0/RTC_GPIO0)
/GPIO39: CON1.18, U7.5 (GPI39/SENSOR_VN/ADC1_CH3/ADC_H/RTC_GPIO3)
/PHYAD0: RM1.4.1, U4.13 (RXER/RXD4/PHYAD0)
/PHYAD1: RM2.1.2, U4.7 (RXCLK/PHYAD1)
/PHYAD2: RM2.2.2, U4.8 (RXD3/PHYAD2)
/RMIISEL: RM2.3.2, U4.9 (RXD2/RMIISEL)
/SC0: I²C0.4, R33.2, U6.5 (SC0)
/SC1: I²C1.4, R34.2, U6.7 (SC1)
/SC2: I²C2.4, R35.2, U6.9 (SC2)
/SC3: I²C3.4, R36.2, U6.11 (SC3)
/SC4: I²C4.4, R47.2, U6.14 (SC4)
/SC5: I²C5.4, R48.2, U6.16 (SC5)
/SC6: I²C6.4, R49.2, U6.18 (SC6)
/SC7: I²C7.4, R50.2, U6.20 (SC7)
/SD0: I²C0.3, R29.2, U6.4 (SD0)
/SD1: I²C1.3, R30.2, U6.6 (SD1)
/SD2: I²C2.3, R31.2, U6.8 (SD2)
/SD3: I²C3.3, R32.2, U6.10 (SD3)
/SD4: I²C4.3, R43.2, U6.13 (SD4)
/SD5: I²C5.3, R44.2, U6.15 (SD5)
/SD6: I²C6.3, R45.2, U6.17 (SD6)
/SD7: I²C7.3, R46.2, U6.19 (SD7)
/VDD1A-2A: C12.1, C13.1, C15.1, C16.1, L2.2, LAN1.3 (COM), LAN1.6 (NC), R5.1, R7.1, R8.1, R9.1, R10.1, U4.1 (VDD2A), U4.27 (VDD1A)
/VDDCR: C17.1, C18.1, U4.6 (VDDCR)
GND: C1.2, C3.2, C4.2, C5.2, C6.2, C7.2, C8.2, C9.2, C10.2, C11.2, C12.2, C13.2, C14.2, C15.2, C16.2, C17.2, C18.2, C19.2, C20.1, C21.2, C22.2, C23.1, C24.2, C25.1, C26.1, C27.1, C28.2, C29.1, C30.1, C31.1, C32.1, CON1.2, CON1.19, D2.2 (A), GND1.1 (Pad), I²C0.1, I²C1.1, I²C2.1, I²C3.1, I²C4.1, I²C5.1, I²C6.1, I²C7.1, J1.1, J1.2, MH1.GND1, MH2.GND1, MICRO_SD1.6 (VSS), MICRO_SD1.SH1 (PACK1), MICRO_SD1.SH2 (PACK2), R3.1, R4.1, R6.2, R13.2, R14.2, R19.2, R37.1, R51.2, RESET1.1, RM1.4.2, RM2.1.1, RM2.2.1, RST1.2, T1.2 (E), U1.0 (SHELL), U1.A1 (GND), U1.A12 (GND), U1.B1 (GND), U1.B12 (GND), U2.2 (GND), U3.8 (GND), U4.24 (TXD2), U4.25 (TXD3), U4.33 (GND), U5.2 (GND), U6.1 (A0), U6.2 (A1), U6.12 (GND), U6.21 (A2), U7.1 (GND), U7.15 (GND), U7.38 (GND), U7.39 (THERMAL_PAD); also elsewhere on the board
unnamed: BUT1.2, R51.1
unnamed: C2.2, FET1.1, R1.1, R2.2
unnamed: C3.1, C4.1, LAN1.GND1, LAN1.GND2
unnamed: D3.1 (K), U3.3 (TXD)
unnamed: D4.2 (A), R11.2, U3.4 (RXD)
unnamed: C1.1, J1.3, J1.4, U2.1 (IN)
unnamed: LAN1.AG1 (AG), R5.2
unnamed: LAN1.AY1 (AY), U4.3 (LED1/REGOFF)
unnamed: LAN1.KG1 (KG), U4.2 (LED2/NINTSEL)
unnamed: LAN1.KY1 (KY), R6.1
unnamed: LAN1.7 (RD+), R8.2, U4.31 (RXP)
unnamed: LAN1.8 (RD-), R7.2, U4.30 (RXN)
unnamed: LAN1.1 (TD+), R10.2, U4.29 (TXP)
unnamed: LAN1.2 (TD-), R9.2, U4.28 (TXN)
unnamed: LED1.1 (K), R37.2
unnamed: MICRO_SD1.2 (CD/DAT3/CS), R21.2, R38.2
unnamed: MICRO_SD1.5 (CLK/SCLK), R39.2
unnamed: MICRO_SD1.7 (DAT0/DO), R40.2
unnamed: MICRO_SD1.8 (DAT1/RES), R24.2, R41.2
unnamed: MICRO_SD1.1 (DAT2/RES), R25.2, R42.2
unnamed: C24.1, L3.2, MICRO_SD1.4 (VDD)
unnamed: PWRLED1.1 (K), R14.1
unnamed: Q2.1 (B), R15.2
unnamed: Q2.2 (E), R16.1, U3.16 (RTS#)
unnamed: Q3.1 (B), R16.2
unnamed: Q3.3 (C), R17.1
unnamed: Q3.2 (E), R15.1, U3.15 (DTR#)
unnamed: R1.2, T1.3 (C)
unnamed: R4.2, U1.A5 (CC1)
unnamed: R3.2, U1.B5 (CC2)
unnamed: U1.A7 (DN1), U1.B7 (DN2), U3.7 (UD-)
unnamed: U1.A6 (DP1), U1.B6 (DP2), U3.6 (UD+)
unnamed: C7.1, R12.1, U3.5 (V3)
unnamed: C8.1, Q1.1, U3.9 (XI)
unnamed: C9.1, Q1.2, U3.10 (XO)
unnamed 91: C20.2, R18.1, RESET1.2, U4.19 (NRST); also elsewhere on the board
unnamed: R19.1, U4.32 (RBIAS)
unnamed: R27.2, U6.3 (~RESET)

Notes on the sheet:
EMAC
Any GPIO
LED
GPIO0:
Power Supply
+5V_Only!!!
Internal Bootstrapping Resistors
Debugging Log on U0TXD During Booting
Auto program
Pull-Up
GPIO15/MTDO
Rising-edge:Output
For more information refer to esp_wroom_32_datasheet_en.pdf.
I2C mux
VSPIQ_in/_out
SD/MMC Card
USB to UART
Software Selectable Pins
Rising-edge:Input
Pull-Down
Default
VSPI_CS0_in/_out
VSPI_CS1_out
Pin
Falling-edge:Output
I2CEXT1_SDA_in
EMAC_MDO_out
Voltage of Internal LDO(VDD_SDIO)
SD-Card's signals were connected here for to be available on the extension and used like GPIOs when SD card is not present.
Extension
Booting Mode
I2CEXT0_SDA_in
1.8V
3.3V
U0TXD Silent
I2C
GPIO2
GPIO5\PHY_PWR
Buttons
EMAC_COL_out

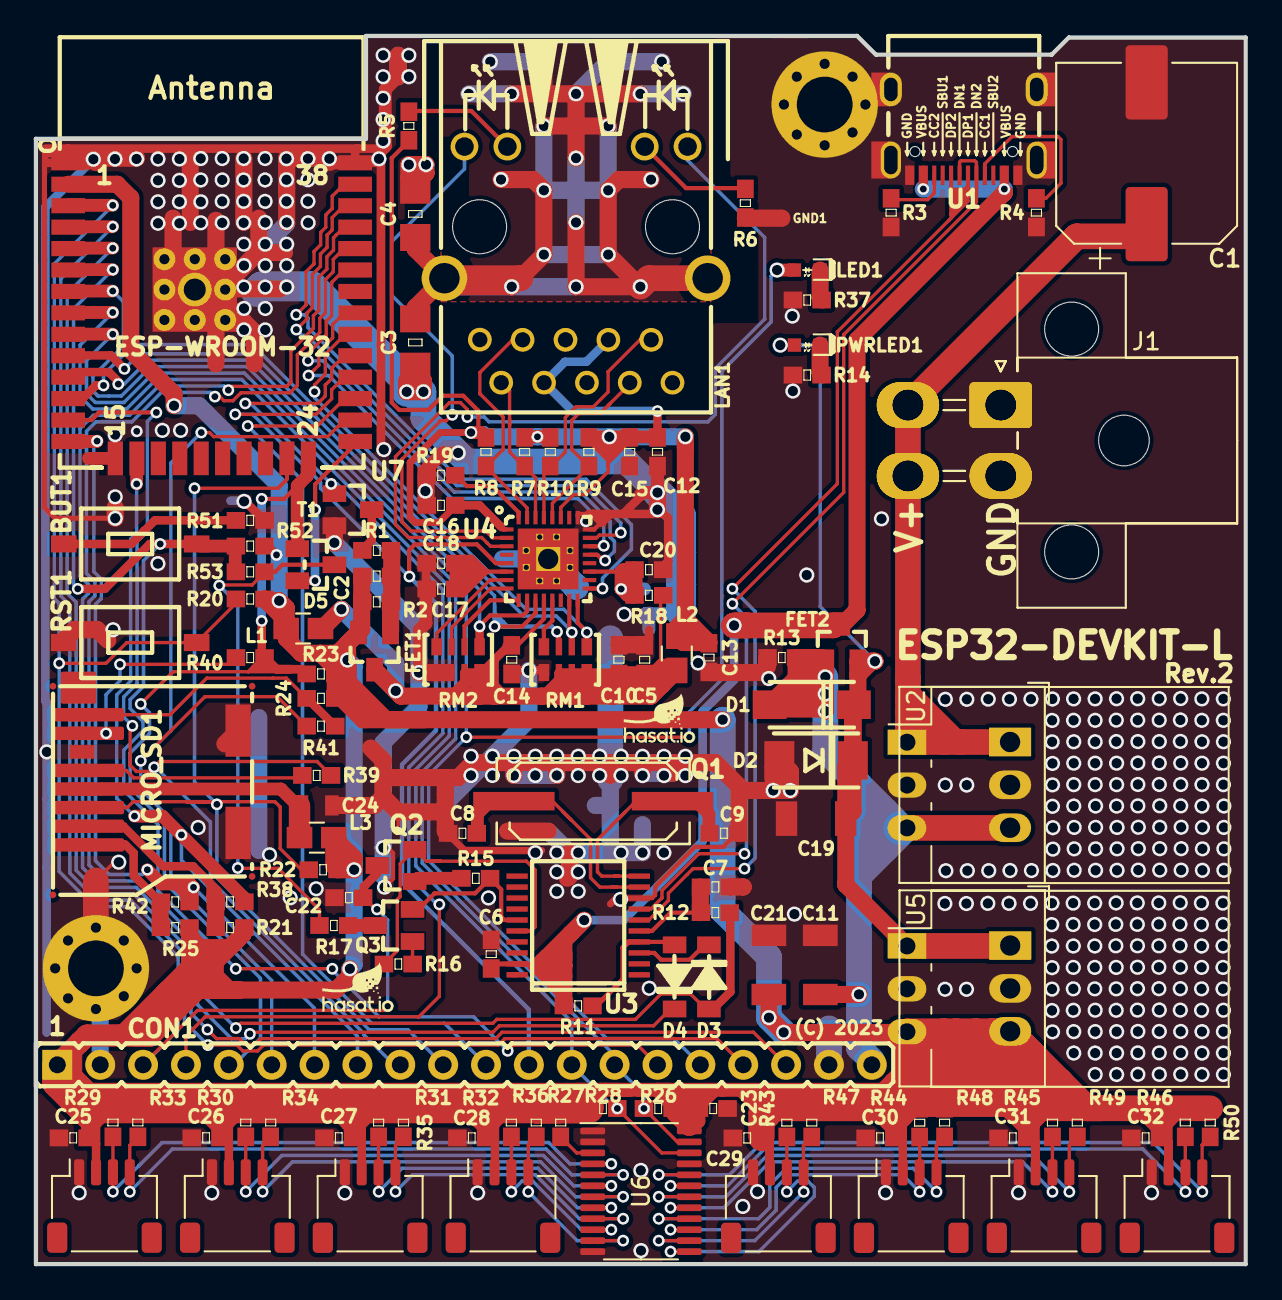
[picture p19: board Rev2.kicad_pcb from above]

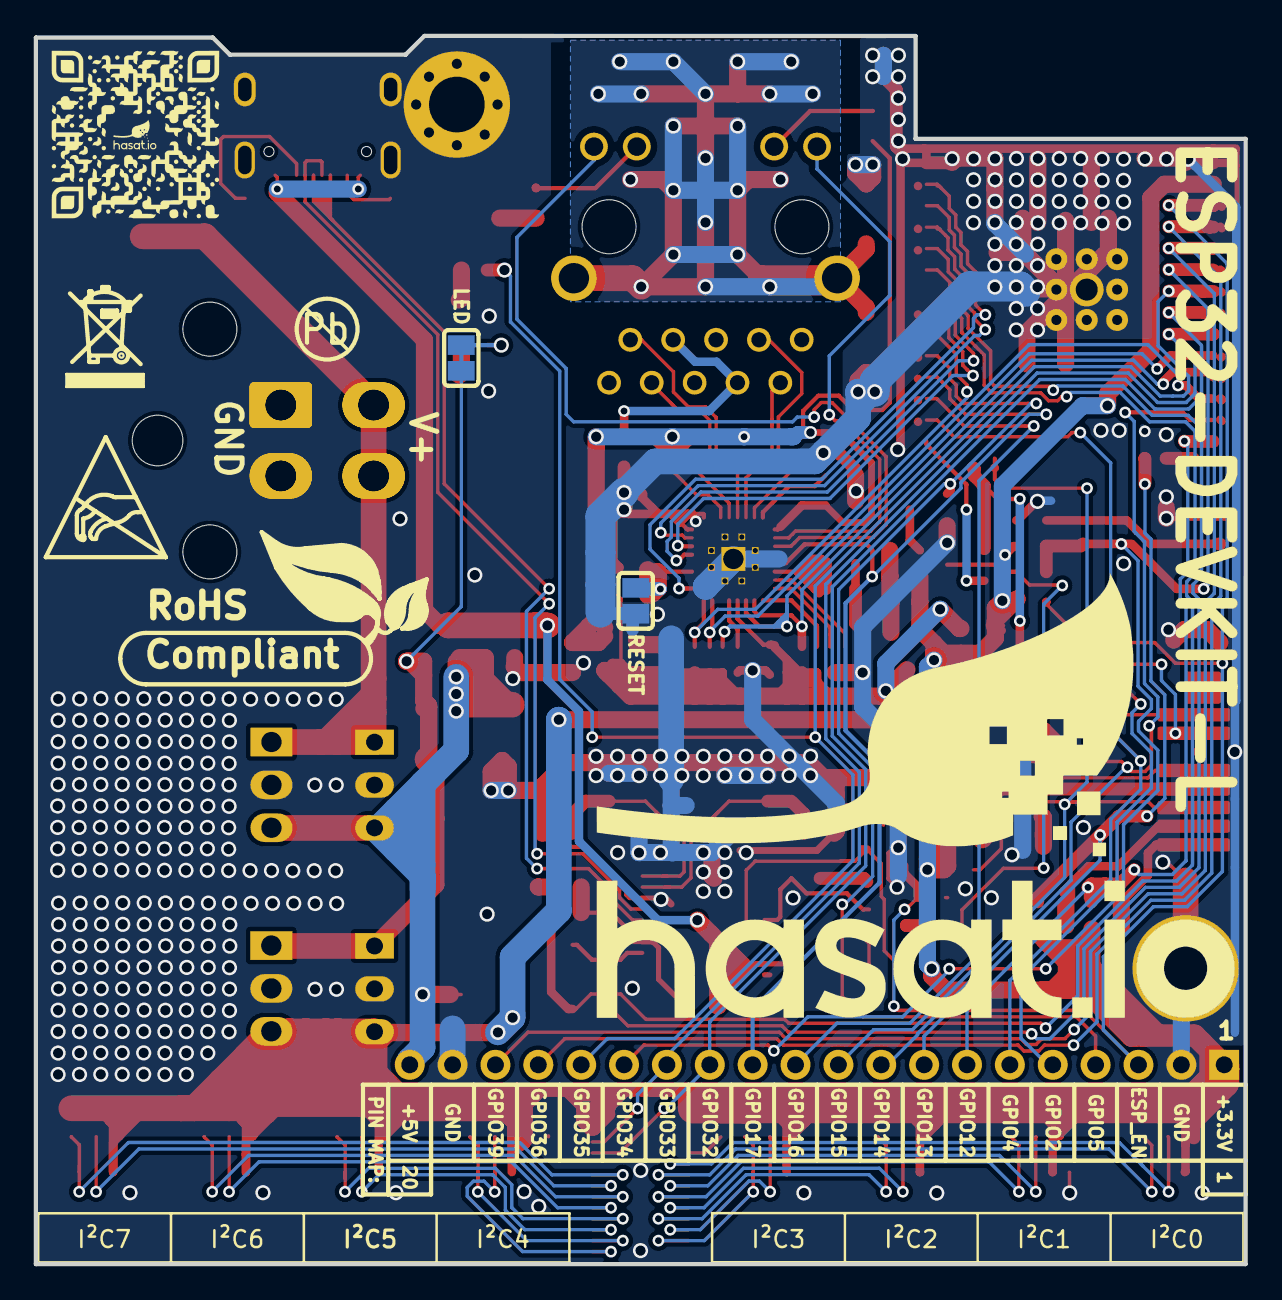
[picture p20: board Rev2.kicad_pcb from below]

Board: 2 copper layers, 71.7 x 72.8 mm, 133 parts (6 on the bottom side), 94 nets.

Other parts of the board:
LED: Closed; SJ
RESET: Opened; SJ
Sign-Antistatic: Val**; LOGO_ANTISTATIC_1
Sign-RecyclBin: LOGO_RECYCLEBIN_1
Sign_Pb-Free: LOGO_PBFREE
Sign_RoHS: Val**; LOGO_ROHS_1

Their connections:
+5V: LED.1, LED.2; also elsewhere on the board
GND: RESET.1; also elsewhere on the board
unnamed 91: RESET.2; also elsewhere on the board

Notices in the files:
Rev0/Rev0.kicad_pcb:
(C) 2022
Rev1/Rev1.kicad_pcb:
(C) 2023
